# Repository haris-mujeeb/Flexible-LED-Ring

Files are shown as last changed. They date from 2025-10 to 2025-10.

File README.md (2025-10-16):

# 🌈 Flexible-LED-Ring: Ultra-Low-Power (ULP) Control System

A highly energy-efficient controller built around the **STM32L011F4U6TR** microcontroller, designed for long-term battery operation. This project demonstrates advanced **Ultra-Low-Power (ULP)** techniques by driving a variable-frequency LED whose rate is controlled by an analog voltage input (ADC), minimising average current draw.

## ⚡ Core Low-Power Architecture

The system achieves microamp-level consumption by spending the maximum possible time in deep sleep modes, delegating all timing tasks to autonomous, low-frequency peripherals.

| Feature | Low-Power Implementation | Power Rationale |
| :--- | :--- | :--- |
| **System Clock** | **MSI @ 4.2 MHz (Scale 3)** | Runs the core voltage at the lowest possible level ($\approx 1.2\text{ V}$) for maximum efficiency in **Run Mode** and fast processing upon wake-up. |
| **Deep Sleep Mode** | **Stop Mode** (0.54 µA with RAM retention) | CPU is halted while the **LPTIM** continues to run autonomously, managing the blinking schedule. |
| **Variable Timing** | **LPTIM (Low Power Timer)** | Replaces high-consumption `HAL_Delay()` with a hardware timer clocked by the $\mathbf{LSI}$ (Low-Speed Internal oscillator). |
| **LED Duty Cycle** | Fixed **15ms Pulse** | The LED is only briefly turned ON, drastically reducing the single largest current draw source. |
| **I/O Gating** | **ADC\_EN (PA7)** control | External circuitry (e.g., analog front-end) is powered ON **only** during the brief ADC conversion window, minimising external leakage. |

## ✨ Functionality

### LED Control:
* **Variable Blink Rate:** The LED blink frequency is dynamically adjusted based on the **ADC value** (0-4095).
* **Low Duty Cycle:** A fixed $\mathbf{5\text{ ms}}$ pulse ensures energy efficiency across all blink frequencies.
* **Deep Sleep Toggle:** The single external switch (SW1/WKUP1) is used to manage the MCU's power state.
    * **First Press:** Activates the system (blinking begins/resumes).
    * **Second Press:** Deactivates blinking, putting the system into **Standby Mode** ($\approx 0.23\text{ µA}$) until the next press.

### 🔌 Charging Mechanism:
* ⚡ Utilises pogo pins for easy connection and charging.
* 💡 Charging LEDs illuminate when the pogo pins are connected and the battery is charging, turning off once fully charged.

## 🔬 Validation and Tools

The power consumption profile was rigorously measured using the **Nordic Power Profiler Kit II (PPK II)** to validate the efficacy of the **Stop Mode** and **Standby Mode** routines.

https://github.com/user-attachments/assets/664f258f-f0d6-4ddf-a007-7cb5bbc9106d

## 💻 Code:
Using ST-Link via Serial Wire debug mode, the program can be flashed onto the  highly energy-efficient STM32L011F4U6TR Microcontroller.

https://github.com/user-attachments/assets/1e935329-2498-4105-b1bf-f483a7316e35

## Assembly:
The PCB can be folded into a ring as shown below:

Assembly_1

**References:**
- For setting up SysTick properly: [see here](https://community.st.com/t5/stm32-mcus-embedded-software/i-know-sounds-dumb-but-how-do-you-configure-systick/td-p/377723)
- For setting up External Interrupts: [see here](https://deepbluembedded.com/stm32-external-interrupt-example-lab/)
- For setting up ADC: [see here](https://controllerstech.com/stm32-adc1-single-channel-polling-mode/)
- For power analysis: [see here](https://www.nordicsemi.com/Products/Development-hardware/Power-Profiler-Kit-2)
- For low-power core configuration (Scale 3, Stop Mode): See [STM32L011x4 Datasheet](https://www.st.com/resource/en/datasheet/stm32l011f4.pdf) and [RM0377 Reference Manual](https://www.st.com/resource/en/reference_manual/rm0377-ultralowpower-stm32l0x1-advanced-armbased-32bit-mcus-stmicroelectronics.pdf)

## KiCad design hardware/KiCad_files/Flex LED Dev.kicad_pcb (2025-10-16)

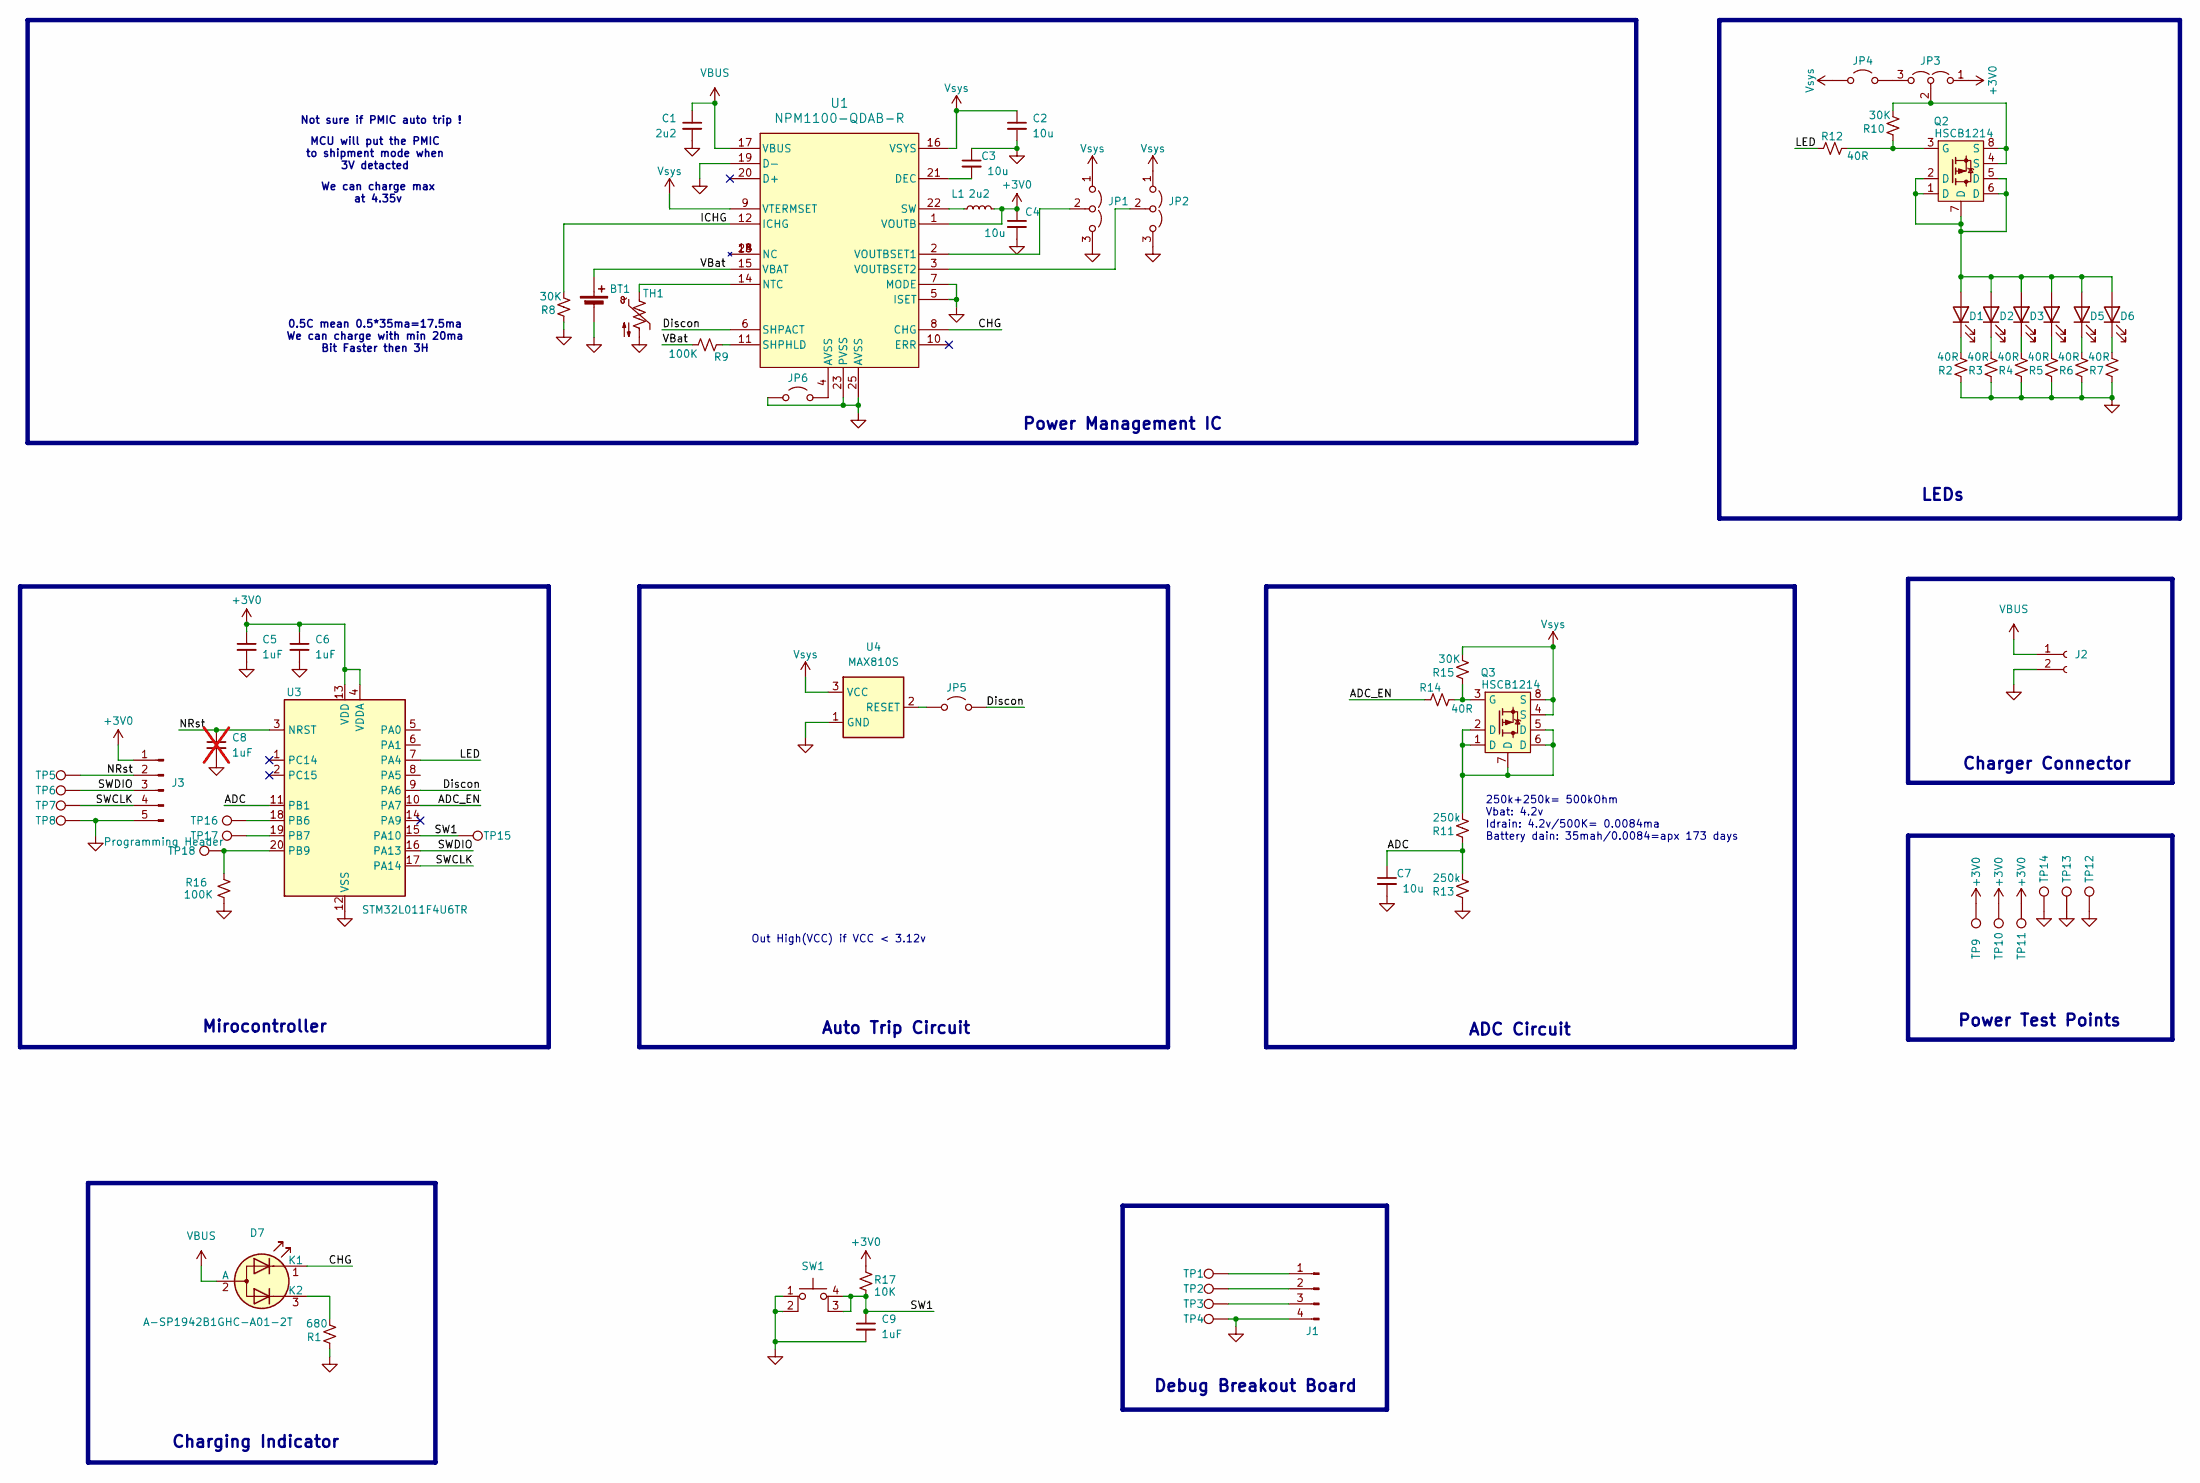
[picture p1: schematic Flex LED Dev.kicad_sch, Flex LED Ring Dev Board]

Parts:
BT1: ICB1040F6; C_0603_1608Metric
C1: 2u2; C_0402_1005Metric
C2, C3, C4, C7: 10u; C_0402_1005Metric
C5, C6: 1uF; C_0402_1005Metric
C8: 1uF; C_0402_1005Metric; not fitted
C9: 1uF; C_0402_1005Metric; Mfr. # CL05A105KA5NQNC; LCSC Part # C52923
D1, D2, D3, D4, D5, D6: LED_0805_2012Metric; Mfr. # APTD2012LSYCK; LCSC Part # C5588998
D7: A-SP1942B1GHC-A01-2T
J1: YZ165615055F-04025-01
J2: Charger Connector; TerminalBlock_Xinya_XY308-2.54-2P_1x02_P2.54mm_Horizontal
J3: Programming Header; PinHeader_1x05_P2.54mm_Vertical
JP1, JP2, JP3: 0402 Jumper; 3_Jump_0402
JP4, JP5, JP6: Jumper_2; Jumper_0402
L1: 2u2; L_0603_1608Metric; Mfr. Part # CIGT252008LM2R2MNE
Q2, Q3: HSCB1214
R1: 680; R_0402_1005Metric; Mfr. # RC0402FR-07820RL; LCSC Part # C137933
R2, R3, R4, R5, R6, R7, R12, R14: 40R; R_0402_1005Metric
R8, R10, R15: 30K; R_0402_1005Metric
R9, R16: 100K; R_0402_1005Metric
R11, R13: 250k; R_0402_1005Metric
R17: 10K; R_0402_1005Metric; Mfr. # RC0402FR-0710KL; LCSC Part # C60490
SW1: TS-1187A-B-A-B
TH1: NTCG103JF103FT1; C_0402_1005Metric
TP1, TP2, TP3, TP4: PH; PinHeader_1x01_P2.00mm_Vertical
TP5: PH; TestPoint_Pad_1.0x1.0mm
TP6, TP7, TP8, TP9, TP10, TP11, TP12, TP13, TP14, TP15, TP16, TP17, TP18: PH; TestPoint_Pad_D1.0mm
U1: NPM1100-QDAB-R; QFN-24-1EP_4x4mm_P0.5mm_EP2.7x2.7mm; Mfr. Part # NPM1100-QDAA-R; LCSC Part # C5816773
U3: STM32L011F4U6TR; ST_UFQFPN-20_3x3mm_P0.5mm
U4: MAX810S; SOT-23-3

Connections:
+3V0: C4.1, C5.1, C6.1, J3.1, JP3.1 (A), L1.2, R17.1, TP9.1, TP10.1, TP11.1, U1.1 (VOUTB), U3.4 (VDDA), U3.13 (VDD)
/ADC: C7.1, R11.1, R13.2, U3.11 (PB1)
/ADC_EN: R14.2, U3.10 (PA7)
/CHG: D7.1 (K1), U1.8 (CHG)
/Discon: JP5.2 (B), U1.6 (SHPACT), U3.9 (PA6)
/ICHG: R8.2, U1.12 (ICHG)
/LED: R12.2, U3.7 (PA4)
/NRst: C8.1, J3.2, TP5.1, U3.3 (NRST)
/SW1: C9.1, R17.2, SW1.3 (K), SW1.4 (A), TP15.1, U3.15 (PA10)
/SWCLK: J3.4, TP7.1, U3.17 (PA14)
/SWDIO: J3.3, TP6.1, U3.16 (PA13)
/VBat: BT1.1 (+), R9.2, U1.15 (VBAT)
GND: BT1.2 (-), C1.2, C2.2, C3.1, C4.2, C5.2, C6.2, C7.2, C8.2, C9.2, J2.2, J3.5, JP1.3 (B), JP2.3 (B), JP6.1 (A), R1.1, R2.1, R3.1, R4.1, R5.1, R6.1, R7.1, R8.1, R13.1, R16.2, SW1.1, SW1.2, TH1.2, TP8.1, TP12.1, TP13.1, TP14.1, U1.5 (ISET), U1.7 (MODE), U1.19 (D-), U1.23 (PVSS), U1.25 (AVSS), U3.12 (VSS), U4.1 (GND)
GNDA: J1.4, TP4.1
unnamed: D1.2 (A), D2.2 (A), D3.2 (A), D4.2 (A), D5.2 (A), D6.2 (A), Q2.1 (D), Q2.2 (D), Q2.5 (D), Q2.6 (D), Q2.7 (D)
unnamed: D1.1 (K), R2.2
unnamed: D2.1 (K), R3.2
unnamed: D3.1 (K), R4.2
unnamed: D4.1 (K), R5.2
unnamed: D5.1 (K), R6.2
unnamed: D6.1 (K), R7.2
unnamed: D7.3 (K2), R1.2
unnamed: J1.1, TP1.1
unnamed: J1.2, TP2.1
unnamed: J1.3, TP3.1
unnamed: JP1.2 (C), U1.2 (VOUTBSET1)
unnamed: JP2.2 (C), U1.3 (VOUTBSET2)
unnamed: JP3.3 (B), JP4.2 (B)
unnamed: JP3.2 (C), Q2.4 (S), Q2.8 (S), R10.2
unnamed: JP5.1 (A), U4.2 (RESET)
unnamed: JP6.2 (B), U1.4 (AVSS)
unnamed: Q2.3 (G), R10.1, R12.1
unnamed: Q3.1 (D), Q3.2 (D), Q3.5 (D), Q3.6 (D), Q3.7 (D), R11.2
unnamed: Q3.3 (G), R14.1, R15.1
unnamed: C3.2, U1.21 (DEC)
unnamed: TH1.1, U1.14 (NTC)
unnamed: R9.1, U1.11 (SHPHLD)
unnamed: L1.1, U1.22 (SW)
unnamed: TP16.1, U3.18 (PB6)
unnamed: TP17.1, U3.19 (PB7)
unnamed: R16.1, TP18.1, U3.20 (PB9)
VBUS: C1.1, D7.2 (A), J2.1, U1.17 (VBUS)
Vsys: C2.1, JP1.1 (A), JP2.1 (A), JP4.1 (A), Q3.4 (S), Q3.8 (S), R15.2, U1.9 (VTERMSET), U1.16 (VSYS), U4.3 (VCC)

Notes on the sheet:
Not sure if PMIC auto trip !
Debug Breakout Board
Power Test Points
LEDs
Charging Indicator
Out High(VCC) if VCC < 3.12v
Power Management IC
0.5C mean 0.5*35ma=17.5ma We can charge with min 20ma Bit Faster then 3H
Auto Trip Circuit
ADC Circuit
250k+250k= 500kOhm Vbat: 4.2v Idrain: 4.2v/500K= 0.0084ma Battery dain: 35mah/0.0084=apx 173 days
Charger Connector
We can charge max at 4.35v
MCU will put the PMIC to shipment mode when 3V detacted
Mirocontroller

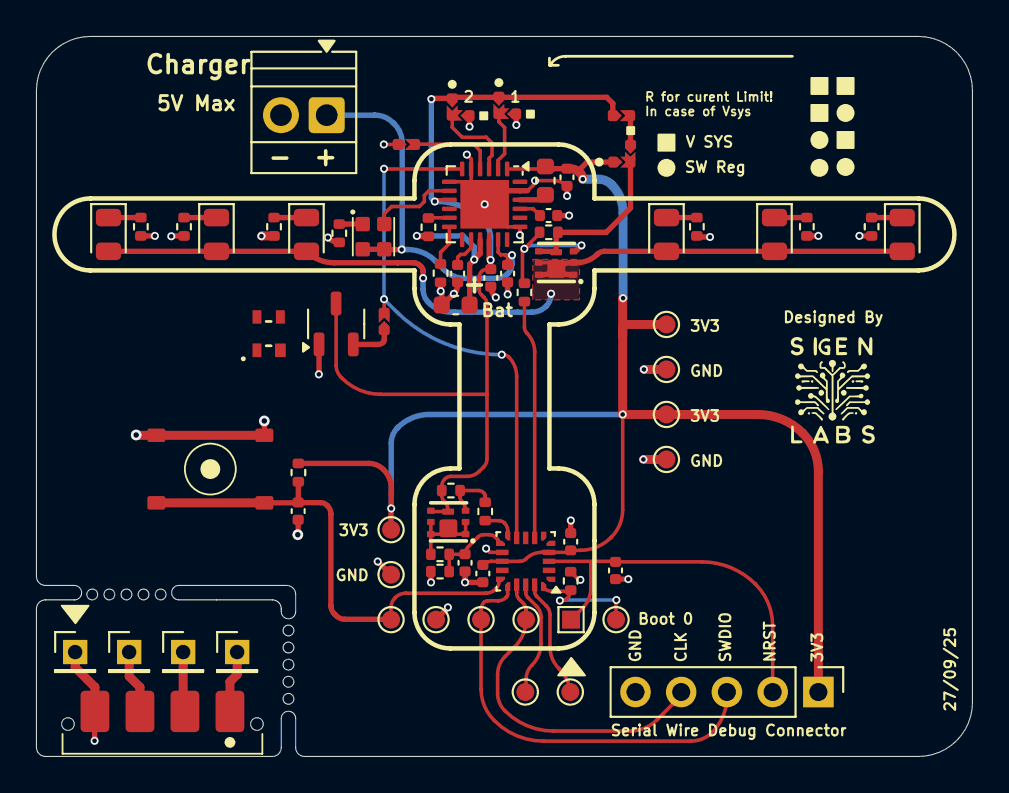
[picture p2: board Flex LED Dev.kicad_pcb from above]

Board: 4 copper layers, 52.0 x 40.0 mm, 71 parts (0 on the bottom side), 43 nets.

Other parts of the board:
mouse-bite-1mm-slot, mouse-bite-1mm-slot#2: VAL**; mouse-bite-slot

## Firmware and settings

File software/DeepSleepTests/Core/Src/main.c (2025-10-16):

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
/* Includes ------------------------------------------------------------------*/
#include "main.h"

/* USER CODE BEGIN PD */
#define ADC_MAX_VALUE       4095
#define MIN_PERIOD_MS       250  // Fastest blink
#define MAX_PERIOD_MS		1000 // Slowest blink
#define DUTY_CYCLE_PERCENT  10
#define ADC_CHECK_INTERVAL  3000 // Check ADC every in milliseconds
#define LPTIM_ARR_VALUE 	554 // Define the ARR value
#define LPTIM_TICK_MS       15   // The time step for the software counter
/* USER CODE END PD */

ADC_HandleTypeDef hadc;

LPTIM_HandleTypeDef hlptim1;

/* USER CODE BEGIN PV */

typedef enum {
    MODE_ACTIVE,
    MODE_STANDBY_HALT
} System_State_t;

volatile System_State_t System_Mode = MODE_ACTIVE;

volatile  uint16_t ADC_Value;

volatile uint32_t led_period_ms = MIN_PERIOD_MS;
volatile uint8_t  led_on = 0;

volatile uint8_t Enter_Sleep_Flag = 0;
//volatile uint8_t System_Halt_Flag = 0;

/* USER CODE END PV */

void SystemClock_Config(void);
static void MX_GPIO_Init(void);
static void MX_ADC_Init(void);
static void MX_LPTIM1_Init(void);
/* USER CODE BEGIN 0 */
/**
 * @brief Calculates a delay time based on the ADC value for variable blinking.
 */
static uint32_t Calculate_Period_ms(uint16_t adc_value)
{
    // Linearly map ADC → 250 .. 1000 ms
    return MIN_PERIOD_MS + (adc_value * (MAX_PERIOD_MS - MIN_PERIOD_MS)) / ADC_MAX_VALUE;
}

/**
 * @brief Performs ADC conversion using Polling and saves the result.
 */
static void Start_ADC_Sequence_Polling(void)
{
    // 1. Power ON ADC Sensor (PA7)
    HAL_GPIO_WritePin(ADC_EN_GPIO_Port, ADC_EN_Pin, GPIO_PIN_SET);

    // 2. ADC Polling Loop
    HAL_ADC_Start(&hadc);
    if (HAL_ADC_PollForConversion(&hadc, 100) == HAL_OK)
    {
        ADC_Value = HAL_ADC_GetValue(&hadc);
    }
    HAL_ADC_Stop(&hadc);

    // 3. Power OFF ADC (saves power, though not yet optimized for low power mode)
    HAL_GPIO_WritePin(ADC_EN_GPIO_Port, ADC_EN_Pin, GPIO_PIN_RESET);

}

/**
 * @brief Prepares peripherals and enters Standby Mode.
 */
static void Enter_Standby_Mode(void)
{
    // 1. Stop Peripherals
    HAL_LPTIM_Counter_Stop_IT(&hlptim1);
    HAL_ADC_DeInit(&hadc);

    // 2. Disable EXTI for WKUP1 pin (PA0)
    HAL_NVIC_DisableIRQ(EXTI0_1_IRQn);

    // 3. Clear Wakeup Flags (Mandatory)
    __HAL_PWR_CLEAR_FLAG(PWR_FLAG_WU); // Clear WUP flag
    __HAL_PWR_CLEAR_FLAG(PWR_FLAG_SB); // Clear Standby flag

    // 4. Enable Wakeup pin 1 (PA0 → rising edge)
    HAL_PWR_EnableWakeUpPin(PWR_WAKEUP_PIN1); // Enable WUP1 (e.g., connected to PA0)

    // 5. Enter Standby Mode (MCU performs a full reset upon wake)
    HAL_PWR_EnterSTANDBYMode();

    // The MCU will not return from this call; it resets when it wakes up.
}

/* USER CODE END 0 */

/**
  * @brief  The application entry point.
  * @retval int
  */
int main(void)
{

  /* USER CODE BEGIN 1 */
	__enable_irq();

  /* USER CODE END 1 */

  /* MCU Configuration--------------------------------------------------------*/

  /* Reset of all peripherals, Initializes the Flash interface and the Systick. */
  HAL_Init();

  /* Configure the system clock */
  SystemClock_Config();

  /* Initialize all configured peripherals */
  MX_GPIO_Init();
  MX_ADC_Init();
  MX_LPTIM1_Init();
  /* USER CODE BEGIN 2 */

  if (HAL_LPTIM_Counter_Start_IT(&hlptim1, LPTIM_ARR_VALUE) != HAL_OK) // ADD
  {
      Error_Handler();
  }

  // *** Standby Wakeup Check (CRITICAL) ***
  if (__HAL_PWR_GET_FLAG(PWR_FLAG_SB) != RESET)
  {
      // MCU woke up from Standby (full reset occurred)
      __HAL_PWR_CLEAR_FLAG(PWR_FLAG_SB);

      // Clear any pending EXTI lines that might have caused the reset
      // (Note: The specific WUP line must be handled depending on connection)
      __HAL_PWR_CLEAR_FLAG(PWR_FLAG_WU);

      // VITAL: Debounce/Hold time after wake-up
      HAL_Delay(100); // Wait 100ms for button to settle

      // Check if the pin is still HIGH (indicating a sustained press or a faulty release)
      if (HAL_GPIO_ReadPin(WKUP1_GPIO_Port, WKUP1_Pin) == GPIO_PIN_SET)
      {
          // Button is still held down, or bouncing.
          // Option A (Safest): Stay in an idle loop or re-enter Standby after a short time
          // Option B (Active mode): Ignore the button press for a grace period

          // For simple fix: Wait for the button to be released, or a maximum grace period
          uint32_t timeout = HAL_GetTick() + 2000; // 2 second grace period
          while (HAL_GPIO_ReadPin(WKUP1_GPIO_Port, WKUP1_Pin) == GPIO_PIN_SET && HAL_GetTick() < timeout)
          {
              // Do nothing, just wait for release
          }
      }

      // Check if the wakeup was intentional (e.g., from a button press)
      // Here, we assume any wakeup from Standby means we enter ACTIVE mode.
      System_Mode = MODE_ACTIVE;


  }

  // Ensure initial state based on current mode
  if (System_Mode == MODE_ACTIVE)
  {
      // Start peripherals required for ACTIVE mode
      Start_ADC_Sequence_Polling(); // Initial ADC read
      led_period_ms = Calculate_Period_ms(ADC_Value);
      HAL_LPTIM_Counter_Start_IT(&hlptim1, LPTIM_ARR_VALUE);
  } else {
      // If not active (should not happen after reset, but safety measure)
      HAL_LPTIM_Counter_Stop_IT(&hlptim1);
      HAL_GPIO_WritePin(LED_GPIO_Port, LED_Pin, GPIO_PIN_SET);
  }



  // Ensure control pins start low
  HAL_GPIO_WritePin(Discon_GPIO_Port, Discon_Pin, GPIO_PIN_RESET);
  HAL_GPIO_WritePin(ADC_EN_GPIO_Port, ADC_EN_Pin, GPIO_PIN_RESET);


  /* USER CODE END 2 */

  /* Infinite loop */
  /* USER CODE BEGIN WHILE */
  while (1)
  {
	if (System_Mode == MODE_STANDBY_HALT)
	{
		// **BUTTON-INITIATED STANDBY (Deepest Sleep)**
		Enter_Standby_Mode();
		// NOTE: The code will never reach here if Standby succeeds; it resets instead.
	}
	else if (Enter_Sleep_Flag)
	{
		// **LED-TIMING RELATED SLEEP (Short duration in Stop Mode)**
		// LPTIM is running, allowing the LPTIM to wake the MCU.
		HAL_PWR_EnterSTOPMode(PWR_MAINREGULATOR_ON, PWR_STOPENTRY_WFI);
		SystemClock_Config(); // Restore fast clock upon LPTIM wakeup
		Enter_Sleep_Flag = 0; // reset flag
	}
    /* USER CODE END WHILE */

    /* USER CODE BEGIN 3 */
  }
  /* USER CODE END 3 */
}

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
/* USER CODE BEGIN 4 */
/**
  * @brief  Period elapsed callback in non-blocking mode
  * @param  htim TIM handle
  * @retval None
  */
void HAL_LPTIM_AutoReloadMatchCallback(LPTIM_HandleTypeDef *hlptim1)
{
    if (hlptim1->Instance != LPTIM1) return;

    static uint32_t led_timer_ms = 0;
    led_timer_ms += LPTIM_TICK_MS;

    // Re-read these constants inside the function or define them locally if needed
    // Assuming led_period_ms is set in main loop
    const uint32_t on_time_ms = 15; // Fixed 15ms pulse
    uint32_t off_time = led_period_ms - on_time_ms;

    if (led_on) // Currently ON
    {
        // Check if ON_TIME has elapsed (5ms)
        // Since we are checking every 15ms, we check if the counter is past the 5ms mark.
        // The LED will be ON for the first 15ms interval, which is > 15ms,
        // ensuring the pulse is at least 5ms wide.
        if (led_timer_ms >= on_time_ms)
        {
            HAL_GPIO_WritePin(LED_GPIO_Port, LED_Pin, GPIO_PIN_SET); // LED OFF
            led_on = 0;
            led_timer_ms = 0;
            Enter_Sleep_Flag = 1;
        }
    }
    else // Currently OFF (waiting for the rest of the period)
    {
        // Check if OFF_TIME has elapsed
        if (led_timer_ms >= off_time)
        {
            Enter_Sleep_Flag = 0;
            HAL_GPIO_WritePin(LED_GPIO_Port, LED_Pin, GPIO_PIN_RESET); // LED ON
            led_on = 1;
            led_timer_ms = 0;
        }
    }

    static uint32_t adc_elapsed_ms = 0;
    adc_elapsed_ms += LPTIM_TICK_MS;
    if (adc_elapsed_ms >= ADC_CHECK_INTERVAL)
       {
           adc_elapsed_ms = 0;

           Start_ADC_Sequence_Polling();  // measure ADC
           led_period_ms = Calculate_Period_ms(ADC_Value);  // adjust blink speed
       }
}


/**
  * @brief Handler for the external switch (WKUP1_Pin) press event (PA10/EXTI).
  */
void HAL_GPIO_EXTI_Callback(uint16_t GPIO_Pin)
{
    if (GPIO_Pin == WKUP1_Pin)
    {
        static uint32_t last_press_tick = 0;
        uint32_t now = HAL_GetTick();

        // Debounce: ignore triggers within 150 ms of the last one
        if (now - last_press_tick < 500)
            return; // Ignore bounce

        last_press_tick = now;

        if (System_Mode == MODE_ACTIVE)
        {
            System_Mode = MODE_STANDBY_HALT;
            Enter_Sleep_Flag = 1;
        }
    }
}
/* USER CODE END 4 */
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


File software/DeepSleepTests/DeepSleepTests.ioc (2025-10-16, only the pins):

Mcu.UserName=STM32L011F4Ux
PA0-CK_IN.GPIO_Label=ADC
PA0-CK_IN.Signal=ADC_IN0
PA13.Signal=SYS_SWDIO
PA14.Signal=SYS_SWCLK
PA4.GPIO_Label=LED
PA4.Signal=GPIO_Output
PA6.GPIO_Label=Discon
PA6.Signal=GPIO_Output
PA7.GPIO_Label=ADC_EN
PA7.Signal=GPIO_Output
PB1.GPIO_Label=WKUP1
PB1.Signal=GPXTI1

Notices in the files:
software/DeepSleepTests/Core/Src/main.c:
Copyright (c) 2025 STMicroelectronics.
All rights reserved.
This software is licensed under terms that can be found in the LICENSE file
